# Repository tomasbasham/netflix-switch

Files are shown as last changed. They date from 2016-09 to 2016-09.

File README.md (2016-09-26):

# Netflix-switch

An electronic schematic and PCB layout for a the lighting array of a Netflix Switch. This PCB is part of a tutorial series where I implement a version of the [original switch](http://makeit.netflix.com/the-switch) myself.

The tutorial series in is 3 parts, [parts 1](https://tomasbasham.co.uk/product%20design/2016/05/12/netflix-and-chill.html), [parts 2](https://tomasbasham.co.uk/product%20design/2016/05/15/netflix-and-chill-part-2.html), and [parts 3](https://tomasbasham.co.uk/product%20design/2016/06/10/netflix-and-chill-part-3.html) and goes through prototyping to assembling the switch using this PCB.

## Printing

The easiest possible way to get a copy of this board printed is to have a PCB fabrication house do it for you. I have had an amazing experience using [OSH Park](https://oshpark.com/) and highly recommend them. Simply upload the compressed gerber files to the website and they will print and ship them to you.



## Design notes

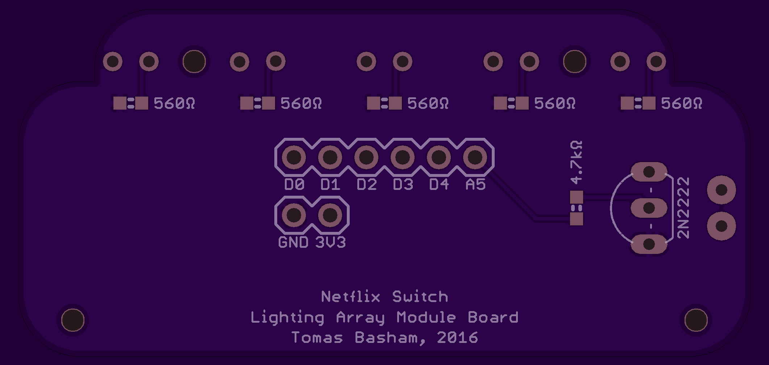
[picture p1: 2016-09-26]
images/netflix-switch-pcb-top.png

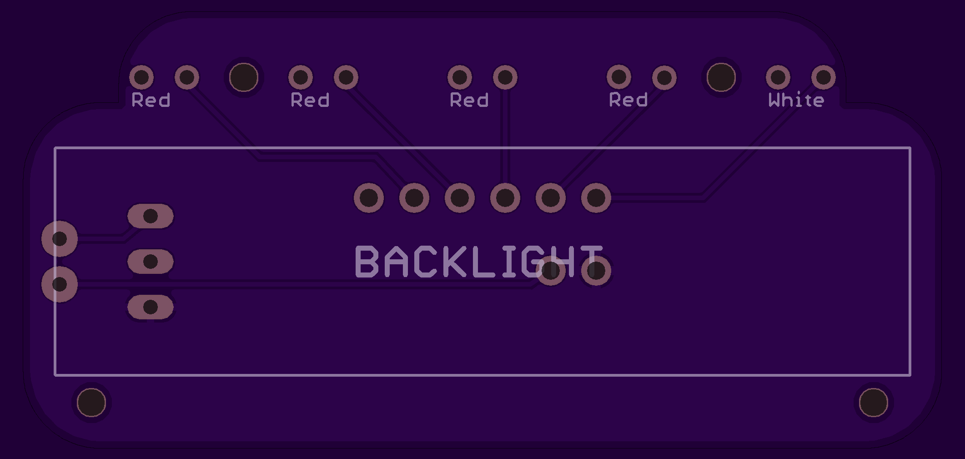
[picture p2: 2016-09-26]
images/netflix-switch-pcb-bottom.png

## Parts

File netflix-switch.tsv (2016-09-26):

Quantity | Value | Package | Order code | Manufacturer | Manuf. Code | Availability | Price (from) | Description
1 | Signal | 1X06 | unknown
1 | Power | 1X02 | unknown
4 | Red | LED3MM-NS | 2217957 | KINGBRIGHT | L-934ID-5V | 4891 | 0.0979 | KINGBRIGHT - L-934ID-5V - LED, RESISTOR- 3MM, RED, 5V
1 | White | LED3MM-NS | 2419077 | VISHAY | VLHW4100 | 4143 | 0.165 | VISHAY - VLHW4100 - LED, WHITE, T-1 (3MM), 7.15CD
5 | 560Ω | 0603 | 1469828 | VISHAY | CRCW0603560RFKEA | 25771 | 0.0045 | VISHAY - CRCW0603560RFKEA - RES, THICK FILM, 560R, 1%, 0.1W, 0603
1 | 4.7kΩ | 0603 | 1469807 | VISHAY | CRCW06034K70FKEA | 65865 | 0.0041 | VISHAY - CRCW06034K70FKEA - RES, THICK FILM, 4K7, 1%, 0.1W, 0603
1 | 2N2222 | TO92-EBC-OVAL | 1611371 | ON SEMICONDUCTOR | P2N2222AG | -6 | 0.0269 | ON SEMICONDUCTOR - P2N2222AG - TRANSISTOR, NPN, 40V, TO-92

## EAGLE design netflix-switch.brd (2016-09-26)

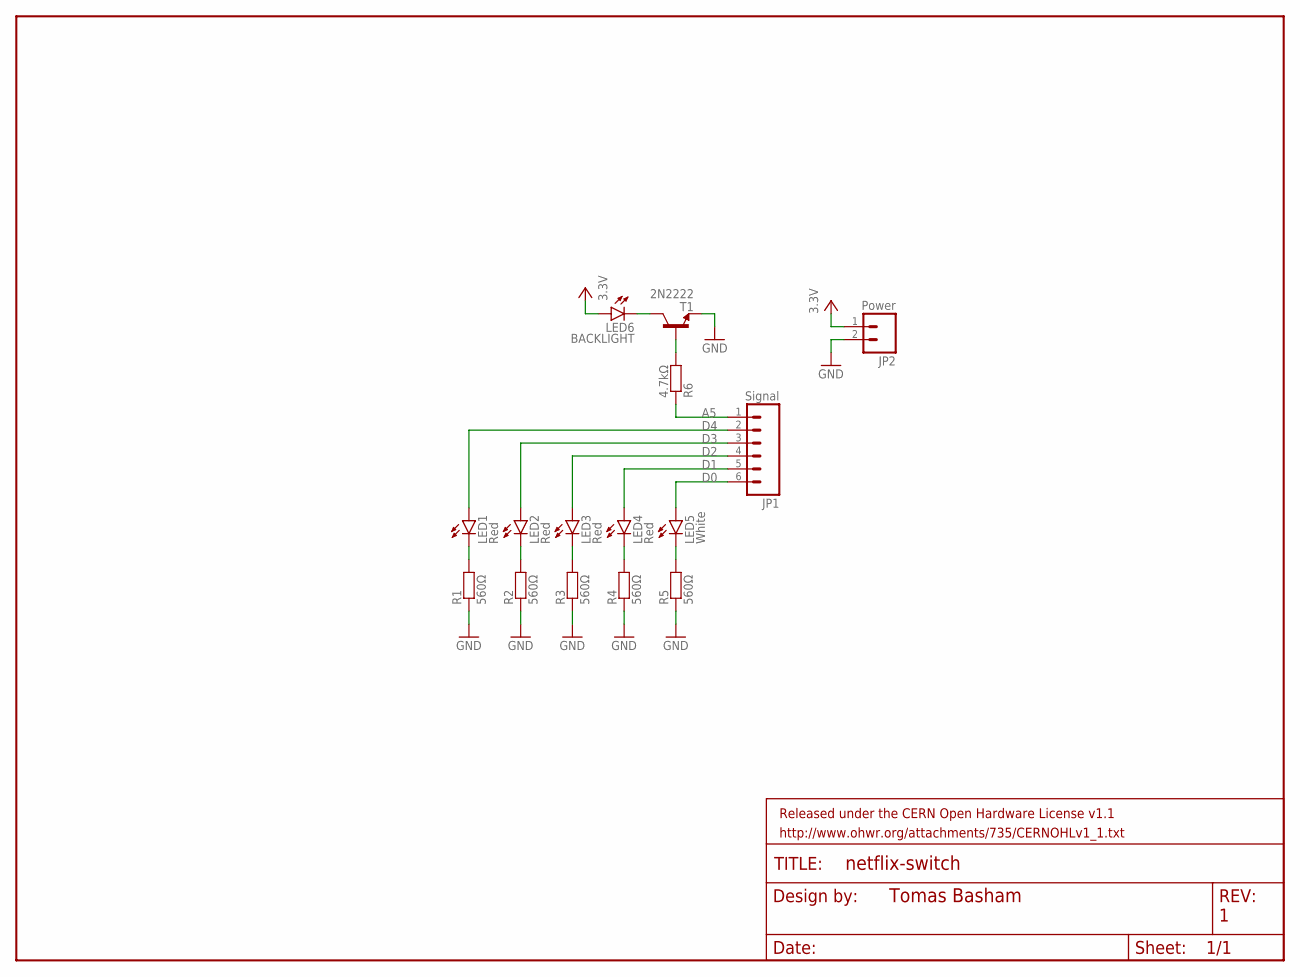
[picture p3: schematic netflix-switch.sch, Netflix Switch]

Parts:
FRAME1: FRAME-LETTER; CREATIVE_COMMONS
JP1: Signal; 1X06
JP2: Power; 1X02
LED1, LED2, LED3, LED4: Red; LED3MM-NS; MPN L-934ID-5V
LED5: White; LED3MM-NS; MPN VLHW4100
LED6: BACKLIGHT; LED5MM-NS
R1, R2, R3, R4, R5: 560Ω; 0603; MPN CRCW0603560RFKEA
R6: 4.7kΩ; 0603; MPN CRCW06034K70FKEA
T1: 2N2222; TO92-EBC-OVAL; MPN P2N2222AG

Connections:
A5: JP1.1, R6.1
D0: JP1.6, LED5.A
D1: JP1.5, LED4.A
D2: JP1.4, LED3.A
D3: JP1.3, LED2.A
D4: JP1.2, LED1.A
GND: JP2.2, R1.1, R2.1, R3.1, R4.1, R5.1, T1.E
unnamed: LED1.K (C), R1.2
unnamed: LED2.K (C), R2.2
unnamed: LED3.K (C), R3.2
unnamed: LED4.K (C), R4.2
unnamed: LED5.K (C), R5.2
unnamed: R6.2, T1.B
unnamed: LED6.K (C), T1.C
VCC: JP2.1, LED6.A

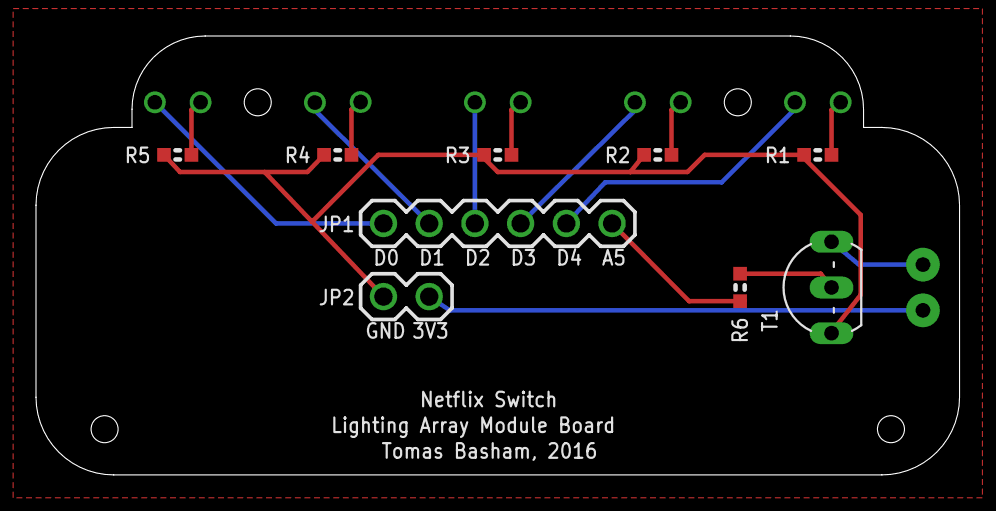
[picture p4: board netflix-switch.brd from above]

Board: 2 copper layers, 51.3 x 24.4 mm, 16 parts (0 on the bottom side), 15 nets.

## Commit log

2016-09-26 Add Netflix Switch breakout board schematics, PCB design and bill of materials
    [netflix-switch.brd, netflix-switch.sch, netflix-switch.tsv]
2016-09-26 Add gerber files to be sent to a fabrication house
    [netflix-switch.GBL, netflix-switch.GBO, netflix-switch.GBS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]

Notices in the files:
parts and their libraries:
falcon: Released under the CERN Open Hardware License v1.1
